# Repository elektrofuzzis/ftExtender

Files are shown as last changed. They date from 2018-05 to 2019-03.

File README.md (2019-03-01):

# ftExtender

<p align="center">Der ftExtender im fertigen Gehäuse</p>

*** english text below ***

Der I²C-Bus am TX(T) ist universell. Es lassen sich Sensoren und Aktoren für alle Anwendungsfälle anschließen und auch der ftDuino kann als preiswertes Erweiterungsboard am TX(T) angeschlossen werden. Der hier vorgestellte ftExtender löst die immer wiederkehrenden Themen
Versorgungspannung, Logikspannung und der Anschluss mehrerer Devices, so dass für den Anschluß von I²C-Geräten nur noch das passende
Kabel benötigt wird.

Das Projekt kann ebenfalls in Arduino und Raspberry Pi Projekten eingesetzt werden.

Im wiki https://github.com/elektrofuzzis/ftExtender/wiki sind Benutzung und Nachbau des ftExtender beschrieben. Der ftExtender ist als fertiges Gerät verfügbar und kann hier bestellt werden: https://gundermann-software.de/shop

Der ftExtender ist ein Community-Projekt von www.ftcommunity.de.

------------------------------------------------------------------------------------------------------------------------------------------

Using the build in I²C-interface of fischertechnik TX and TXT controllers, you could connect all types of I²C devices. You could connect a ftDuino and us it as a simple I/O extension in RoboPro, too. But if you want to use a I²C device, you need to discuss logic levels and a power supply, first. This project solves these problems and you just need some cables to connect your devices.

You could use the ftExtender in your Arduino or Raspberry Pi projects, too.

The wiki https://github.com/elektrofuzzis/ftExtender/wiki describes usage and reprodution of the ftExtender. The ftExtender is available as a ready-made system, too. Please visit: https://gundermann-software.de/shop

This is a community project of www.ftcommunity.de.

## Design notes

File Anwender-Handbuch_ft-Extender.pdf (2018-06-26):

## ft-Extender

ein fischertechnik-kompatibler I²C Extender

Bedienungsanleitung

Christian Bergschneider
Stefan Fuss
Björn Gundermann
Rudenz Schulz

26.06.2018

Projekt-Homepage: https://github.com/elektrofuzzis/ft-Extender

Kontakt: | ft-extender@gundermann.org
Forum: | https://forum.ftcommunity.de/

Einleitung

Aktuell gibt es 3 verschiedene Controller im fischertechnik Umfeld die sich leicht per I²C erweitern lassen.

Dies sind der fischertechnik TX Controller

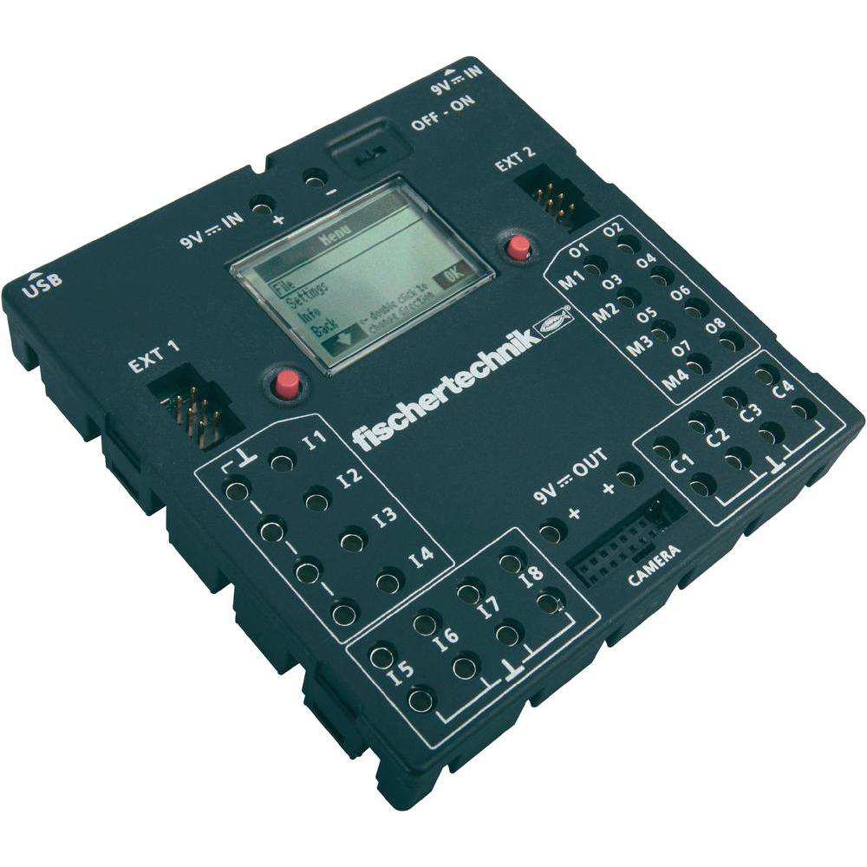
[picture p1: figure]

Der fischertechnik TXT Controller

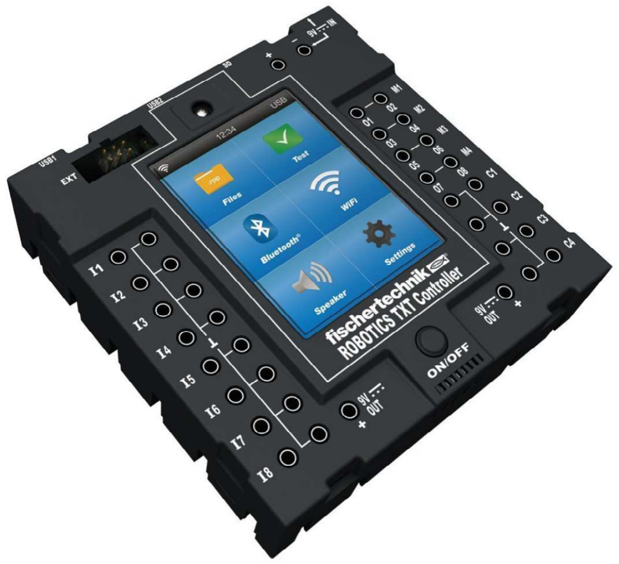
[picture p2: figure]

sowie der ftDuino auf Arduino Basis

An die Controller lassen sich Sensoren und Aktoren für alle Anwendungsfälle anschließen und auch der ftDuino kann als preiswertes Erweiterungsboard am TX(T) genutzt werden. Theoretisch, denn für jedes neue Device müssen die Themen Versorgungspannung und Logikspannung gelöst werden.

Der ft-Extender stellt beide elektrischen Standards und die benötigten Versorgungsspannungen an seinen Anschlüssen zur Verfügung, so dass der Anschluss eines I²C-Devices nur noch ein einfaches Kabel ist.

I²C
I²C ist als Master-Slave-Bus konzipiert. Ein Datentransfer wird immer durch einen Master initiiert; der über eine Adresse angesprochene Slave reagiert darauf. Der TX und TXT-Controller kann immer nur als Master agieren. Der ftDuino kann sowohl Master als auch Slave sein. Die jeweilige Variante wird per Sketch programmiert.

Jedes I²C-fähige IC hat eine vom Hersteller festgelegte Adresse, von der bisweilen die untersten drei Bits (Subadresse genannt) über drei Steuerpins festgelegt werden können. In diesem Fall können bis zu acht gleichartige ICs an einem I²C-Bus betrieben werden. Wenn nicht, müssen mehrere gleiche ICs mit getrennten I²C-Bussen angesteuert oder abgetrennt werden.

Es ist also bei Anschluss mehrerer Sensoren/Aktuatoren darauf zu achten, dass alle Teilnehmer verschiedene IDs haben.

Besitzer eines ftDuinos können die Adresse eines Teilnehmers leicht mit dem folgenden Sketch ermitteln.

Das Testprogramm sucht am I²C-Bus nach angeschlossenen Sensoren und gibt deren Adresse aus.

Da der ftDuino sowohl Master als auch Slave sein kann, ist die Kopplung zweier ftDuinos möglich.

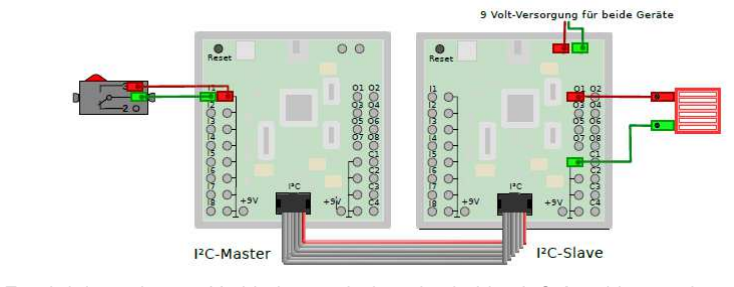
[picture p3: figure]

Es wird dazu eine 1:1-Verbindung zwischen den beiden I2C-Anschlüssen der beteiligten Controller hergestellt. Ein Controller muss in diesem Aufbau als Master konfiguriert werden und einer als Slave. Mehr dazu im Handbuch des ftDuino.

Ist ein TX/TXT Controller im Bus müssen alle anderen Teilnehmer als Slave konfiguriert werden.

Logikspannung & Stromversorgung

Beim Anschluss eines I²C-Devices hat man immer wieder die gleichen Fragestellungen nach Stromversorgung und Logikspannung.

Die ft-typischen 9V können als Stromversorgung nicht direkt verwendet werden. Alle I²C-Devices benötigen entweder 3,3V oder 5V. Diese Spannungen lassen sich mit einem Linearregler und zwei Elkos einfach herstellen.

Das gleiche gilt für die Logikspannung, auch hier gibt es I²C-Devices mit 5 V und mit 3,3 V Logikspannung.

Mit sogenannten Levelshiftern lassen sich Devices mit unterschiedlicher Logikspannung miteinander verbinden. Diese kann man mit zwei MOS-FETs und vier Widerständen selber bauen, oder fertige kleine Platinen kaufen.

Der ft-Extender löst die beiden Probleme, indem er einen Levelshifter und zwei Linearregler auf der Platine hat. Somit können problemlos 5 V- und 3,3 V-Devices ohne Zusatzbeschaltung über ein einfaches Kabel angeschlossen werden.

Als Stromversorgung stehen 250 mA für jedes angeschlossene Device zur Verfügung. Dies ist für den Betrieb von Sensoren völlig ausreichend. Beim Anschluss von Aktoren wie Motoren, Lampen und Servos sind 250 mA schnell erreicht, so dass diese eine eigene Stromversorgung bekommen sollten.

Anschlüsse

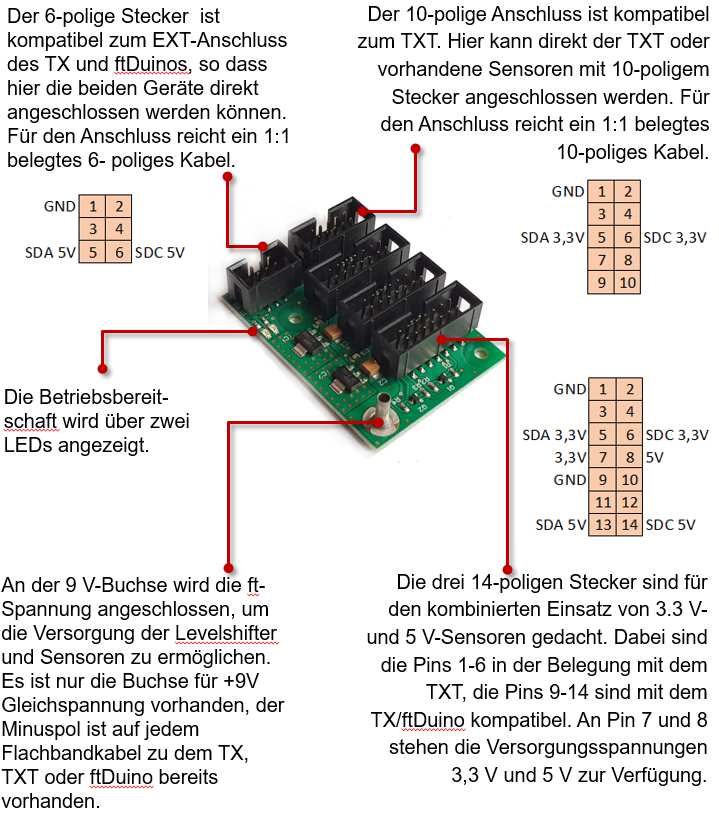
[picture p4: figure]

Anwendungsbeispiele

Für die meisten Beispiele existieren ROBOPro Bibliotheken oder ftDuino Programme. Die Links hierzu finden Sie am Ende des Handbuchs.

TX- und TXT Controller
Der TX-Controller wird immer über ein 1:1 gecrimptes Flachbandkabel am 6-poligen Stecker angeschlossen. Der TXT-Controller wird immer über ein 1:1 gecrimptes Flachbandkabel am 10-poligen Stecker angeschlossen.

Die fischertechnik Firmware der beiden Controller beherrscht leider keinen Multi-Masterbetrieb am I²C-Bus. Deshalb können nicht mehrere TX- oder TXT-Controller über den I²C-Bus zusammengeschaltet werden.

Mit der CFW-Firmware kann der TXT-Controller als Slave-Device programmiert werden. In diesem Fall lassen sich mehrere fischertechnik Controller zusammenschalten.

ftDuino Grundschaltung
Der ftDuino wird wie der TX in der Regel am 6-poligen Stecker über ein 1:1 gecrimptes Flachbandkabel angeschlossen.

Im Gegensatz zu den original fischertechnik Controllern kann der ftDuino sowohl als Master- als auch als Slave-Device programmiert werden. Im Slave-Modus können mehrere ftDuinos am ft-Extender angeschlossen werden.

ftDuino als Erweiterungsboard am TX(T)
Über den ft-Extender lassen sich ftDuinos als Erweiterungsboards an den TX und TXT-Controller anschließen. Dabei wird der oder die ftDuinos als I²C-Slave-Device programmiert und vom original fischertechnik Controller unter ROBOPro gesteuert.

Will man nun einen TXT und einen ftDuino koppeln, so wird wie gewohnt der TXT am 10-poligen Stecker und der ftDuino am 6-poligen Stecker
angeschlossen.

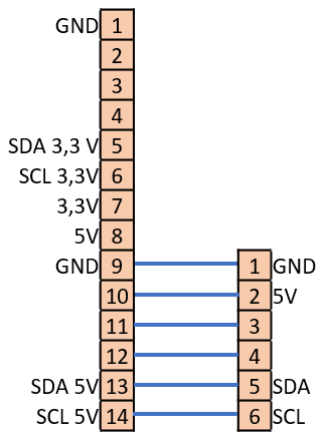
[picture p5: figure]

Soll der ftDuino mit dem TX gekoppelt werden, oder
sollen | mehrere | ftDuinos | an | einem | Controller
angeschlossen werden, so müssen die ftDuinos an den 14-poligen Steckern angeschlossen werden.

Dazu wird ein 6-poliges Flachbandkabel auf die letzten 6 Anschlüsse einer 14-poligen Buchse gecrimpt. Das zweite Ende des Flachbandkabels erhält eine 6-polige Buchse.

0,96“ OLED-Display
Es gibt von verschiedenen Herstellern aus der Arduino-Szene fertige OLED-Displays mit I²C-Bus-Interface.

Alle Implementierungen haben einen 4poligen Stecker mit GND, VCC/VDD, SDA und SCL. Sie funktionieren in der Regel sowohl mit 3,3V als auch mit 5V. Wer sich nicht sicher ist, startet erst einmal mit 3,3V.

Achtung, die Steckerbelegung des OLED Displays kann je nach Hersteller abweichend sein!

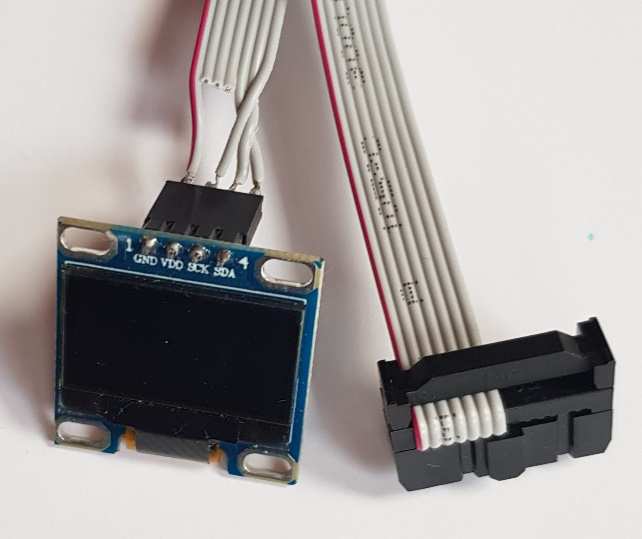
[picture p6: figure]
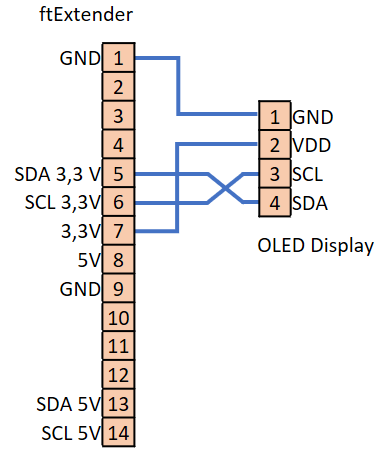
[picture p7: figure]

Um das Kabel leichter crimpen zu können kann auch ein 14-poliges Flachbandkabel AWG28 verwendet werden. Nicht benötigte Kabel können dann später gekappt werden. Dies vereinfacht das crimpen des Kabels. Das gecrimpte Kabel sollte auf jeden Fall danach noch einmal geprüft werden.

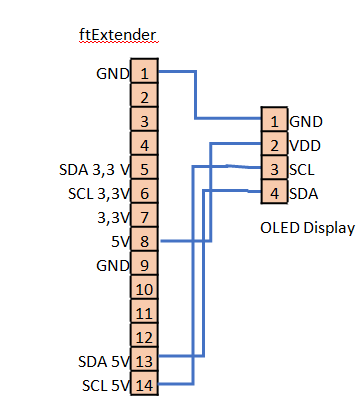
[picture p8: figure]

Die Belegung für ein Display mit 5Vsieht wie folgt aus.

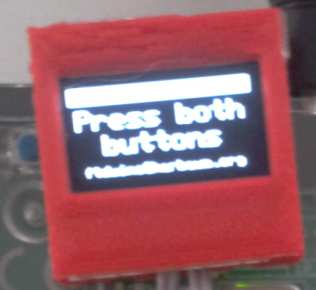
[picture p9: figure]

Ein Fertiggerät (ft-OLED) aus Display und 3D-gedrucktem
Gehäuse | kann | über | ft-extender@gundermann.org
bezogen werden. Wahlweise mit 6pol oder 14pol

Pfostenbuchse.

ft-Extender kaskadieren

Sind alle Buchsen des ft-Extenders belegt, so kann man auch mehrere ft-Extender hintereinander schalten. Dazu können entweder die 10-poligen oder die 6-poligen Stecker mit einen 1:1-Kabel verbunden werden.

Mit einem 6-poligen und einem 10-poligen Kabel können auch drei ft-Extender zusammengeschaltet werden. Wichtig ist, dass keine Schleifen entstehen: zwei ft-Extender, die sowohl mit einem 6-poligen als auch einem 10-poligen Kabel verbunden sind funktionieren nicht. Dies ist auch der Grund warum ein 14-poliges Kabel ebenfalls nicht funktioniert – hier sind bereits beide Signalpegel enthalten und würden eine Schleife bilden.

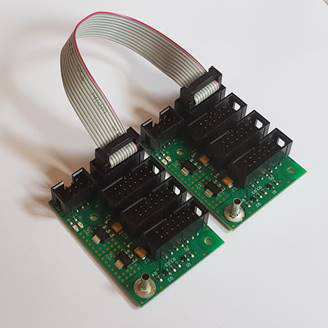
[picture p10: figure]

8x8 BiColor LED Matrix

Die 8x8 BiColor LED Matrix von Adafruit ist eine LED Matrix bestehend aus 64 Pixeln. Jedes Pixel besteht aus einer 2-Farb-LED und kann somit die Farben rot, grün und orange darstellen. Die Ansteuerung der LED Matrix erfolgt über den I²C-Bus mit einem 5V-Signal.

Da eine Versorgungsspannung benötigt wird, erfolgt der Anschluss am 14-poligen Stecker:

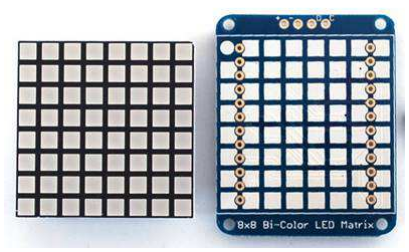
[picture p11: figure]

Adafruit hat neben der beschriebenen 8x8-BiColor Matrix auch noch einfarbige Matrizen, Bargraphs und 7-Segmentanzeigen im Programm. Das elektrische Anschlussschema und der verwendete I²C-Bus-Steuerbaustein ist für alle Typen gleich. Der ROBOPro-Treiber funktioniert mit allen 8x8-Matrizen. Bei den anderen Typen funktioniert die Ansteuerung des I²C-Bus-Steuerbausteins und das Ein- und Ausschalten einzelner LEDs. Eine ausführliche Beschreibung der LED-Matrix- und 7-Segmentanzeigen von Adafruit finden Sie im Link Kapitel.

Sparkfun 7-Segmentanzeige

Mit einem anderen Treiberbaustein ausgestattet ist die 7-Segmentanzeige COM-11440 von Sparkfun. Sie kann wahlweise mit 3,3V oder mit 5V betrieben werden. In diesem Beispiel wird der 5V-Anschluss verwendet. Der Anschluss am 14-poligen Stecker:

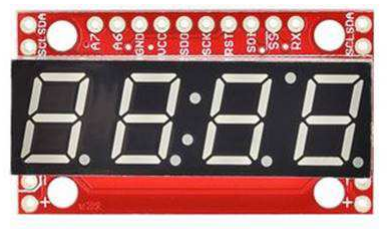
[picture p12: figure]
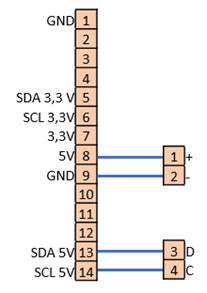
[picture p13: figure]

Der Baustein und seine Ansteuerung ist in der ft:pedia 4/2016 ab Seite 84 im Detail von Dirk Fox beschrieben. Der Link zu den Treibern findet sich im Link Kapitel.

VL53L0X LIDAR-Distanzsensor

Dieser Sensor ist eine interessante Alternative zu Ultraschallsensor. Statt Schall wird hier mit einem gemessen

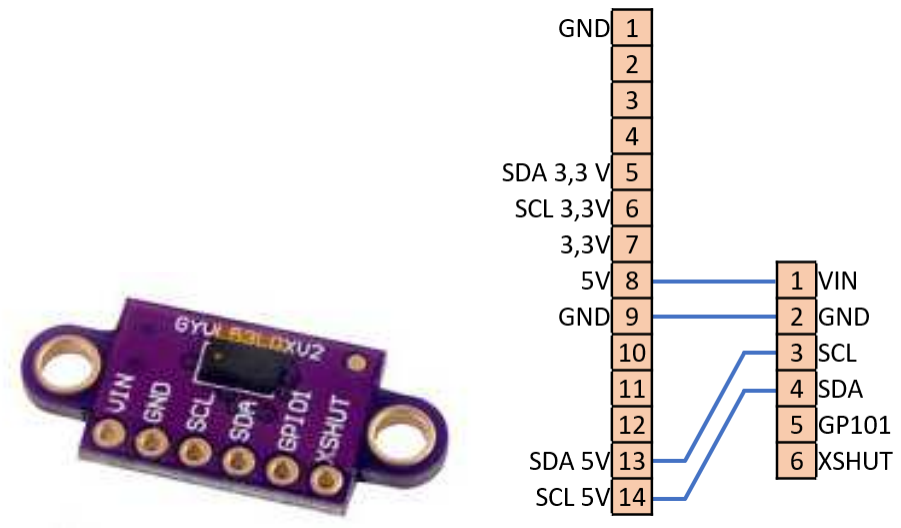
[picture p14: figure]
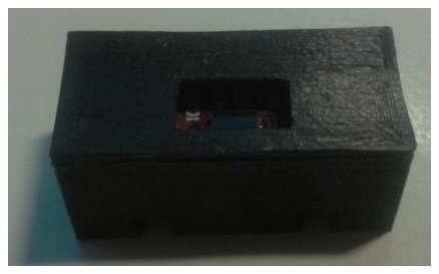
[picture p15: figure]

Ein Fertiggerät (ft-LIDAR) aus gedrucktem Gehäuse kann über extender@gundermann.org

TCS34725 RGB Sensor
Der TCS34725 ist ein hochwertiger Farbsensor und er
dem fischertechnik Farbsensor (der nur einen Hell
weniger störlichtanfällig und verlässlichere Farbbestimmung. sowohl mit 3,3V als auch mit 5V betrieben werden.

dem fischertechnik
Laserlicht die Entfernung

Sensor und 3Dftbestellt werden.

möglicht, im Gegensatz zu
igkeitswert liefert), eine schnellere, Der Sensor kann

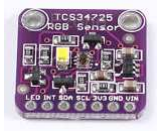
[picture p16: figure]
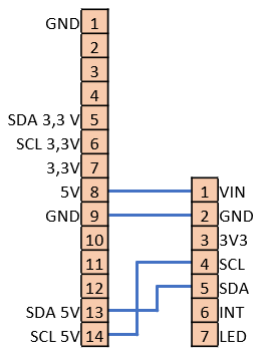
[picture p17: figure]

Fischertechnik Kombisensor und TXT Smart Home Senso

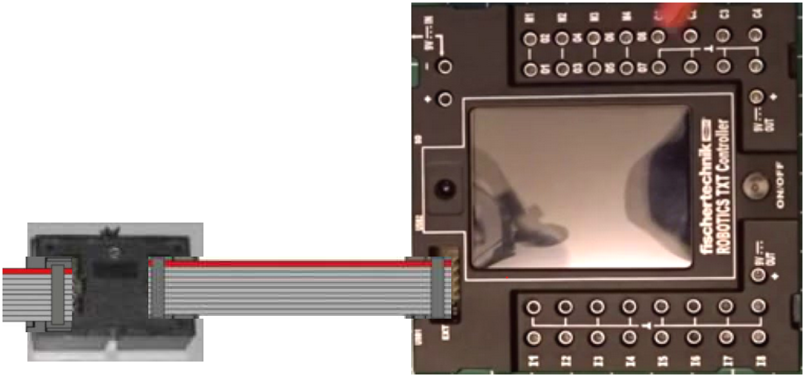
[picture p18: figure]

Diese Sensoren kommen mit dem
Weiterhin verfügen diese Sensoren über 2 Wannenstec über die beiden Stecker 1:1 geschleift, so dass es Möglichkeiten gibt:

TXT

- Der Sensor wird über ein 10 über ein zweites 10-poliges Kabel.
- Der Sensor wird am 14
ersten 6 Pins von 14
Steckers verbunden. Die Pins 7 verbunden werden!

r

für den TXT gebräuchlichen 10 poligen Kabel. ker. Das I²Cfür den Anschluss mehrere

-poliges Kabel angeschlossen, der
poliges Kabel.
-poligen Stecker angeschlossen. Dabei werden die -poligen Stecker mit den ersten 6 Pins des 10
-10 des 10-poligen Steckers dürfen

-Bussignal ist

ft-Extender

-poligen
nicht

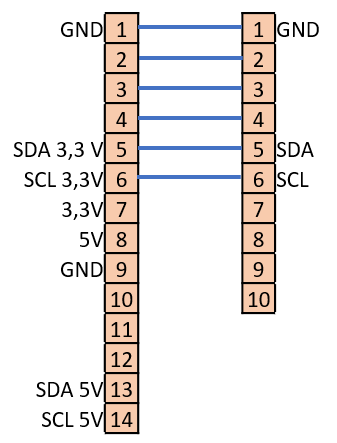
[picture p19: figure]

TX und ftDuino

TX bzw. ftDuino werden über ein 6

- Der Sensor wird über ein 10
- Der Sensor wird am 14
ersten 6 Pins von 14
Steckers verbunden. Die Pins 7 verbunden werden!

-poliges Kabel am ft-Extender angeschlossen.

-poliges Kabel am ft-Extender angeschlossen. -poligen Stecker angeschlossen. Dabei werden die -poligen Stecker mit den ersten 6 Pins des 10
-10 des 10-poligen Steckers dürfen nicht

angeschlossen.

angeschlossen.

-poligen

Crimpen von Flachbandkabeln

Die Pfostenbuchsen an den Flachbandkabeln lassen sich auch ohne Spezialwerkzeug crimpen.

An der Buchse ist Pin1 mit einem Pfeil markiert. Für ein 1:1-Kabel wird hier die farblich markierte Ader des Flachbandkabels angelegt. Ob das Kabel links oder rechts aus der Buchse geführt wird ist völlig egal, die Pinbelegung am Kabel bleibt gleich. Wichtig ist, dass das Kabel möglichst senkrecht zur Buchse geführt wird, damit zu keinem Kurzschluss kommt.

Danach wird entweder mit einer Wasserpumpenzange oder mit dem Schraubstock der Sicherungsclip auf die Buchse gedrückt. Dabei wird das Flachbandkabel automatisch gecrimpt. Bitte nicht mit zu viel Kraft, die Sicherungsclips brechen sonst gerne.

I²C Sensoren mit direktem Anschlußkabel an TX/ftDuino als Beispiele

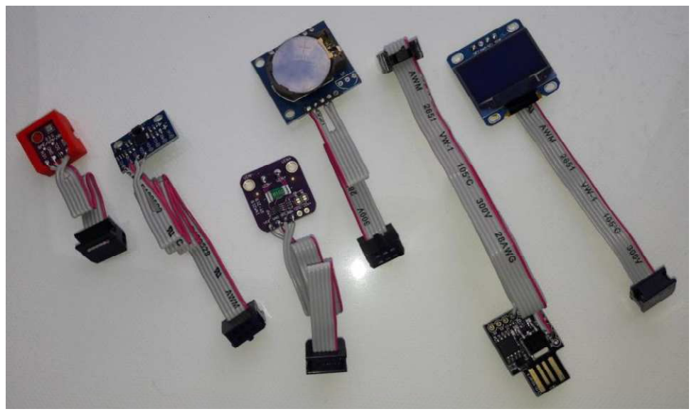
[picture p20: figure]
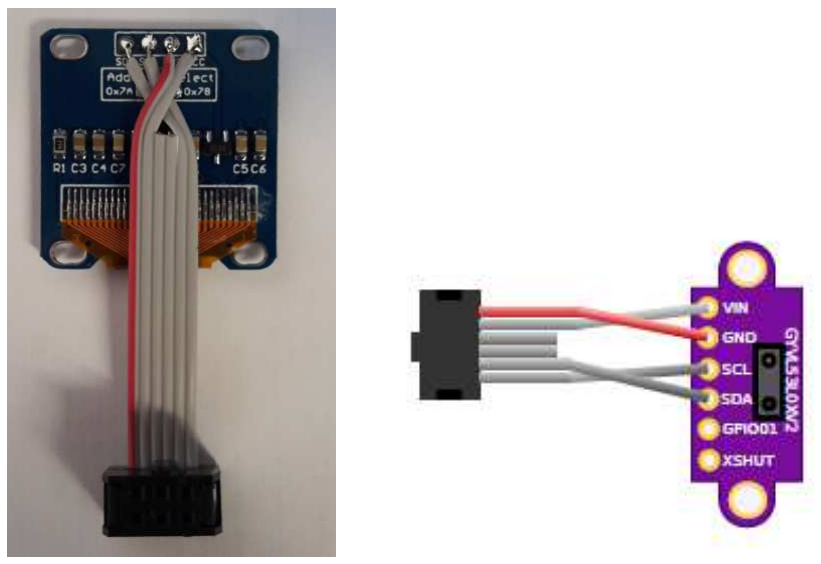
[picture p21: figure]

Technische Daten

Alle Flachbandkabel benötigen einen Leitungsabstand von 1,27mm.

Die Pfostenbuchsen haben ein Rastermaß von 2,54mm.

Der Spannungsregler hat eine maximale Ausgangsleistung von ca. 800mA. Eine höhere Gesamtlast kann also nicht an den 3 Anschlüssen verwendet werden. Normale Sensoren liegen jedoch deutlich unter diesem Wert.

An der 9V Buchse ist die 9V Versorgung des TX, TXT oder ftDuino mit den normalen ft-Kabeln und deren Stecker anzuschließen.

Steckerbelegungen kompakt:

6-pol TX/ftDuino | 10-pol TXT | 14-pol Sensoren/Aktuatoren

Pfostenbuchsen

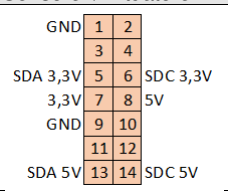
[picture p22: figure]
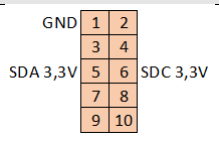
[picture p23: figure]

Die notwendigen Pfostenbuchsen können wie das Flachbandkabel direkt mitbestellt werden.

Eine Suche nach „Pfostenbuchse, 6-polig„ findet passende Treffer. Als reines Beispiel sei in der Anlage der Link vermerkt. Es besteht keine Verbindung zu der genannten Firma. Alternative Bezugsquellen existieren ebenfalls.

Wichtig ist es auf das Rastermaß von 2,54mm zu achten.

Anhang A: Schaltplan

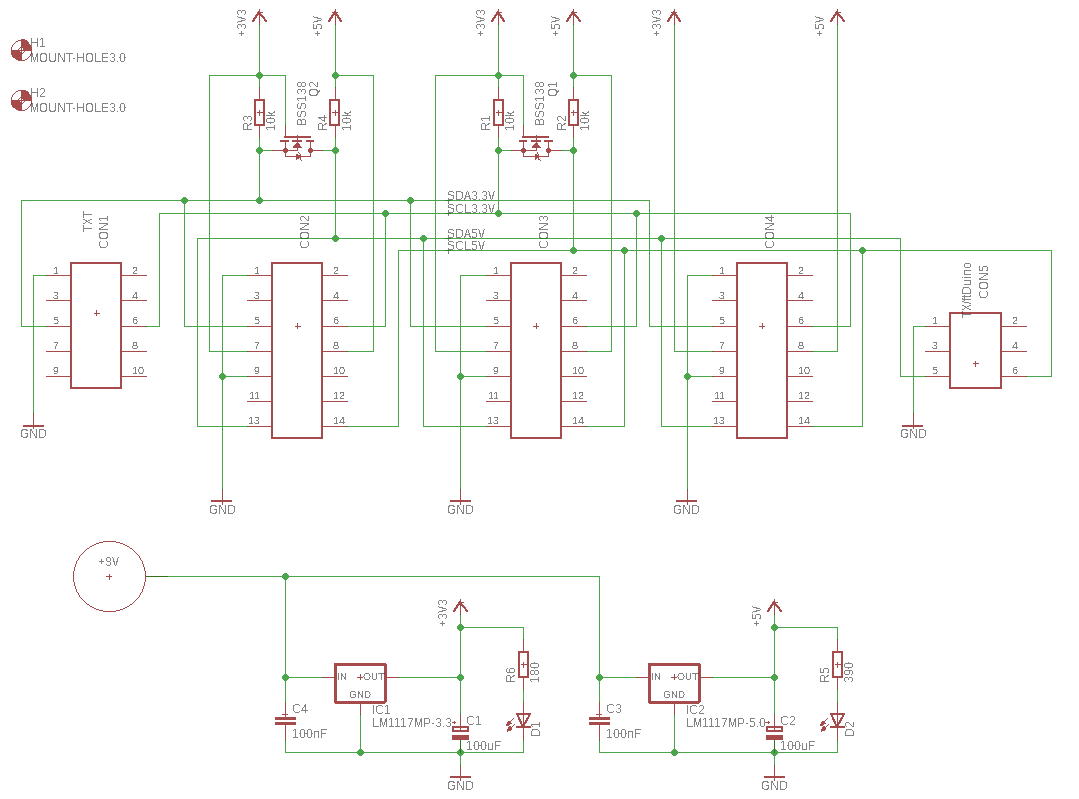
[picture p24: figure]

Links

Hier eine Liste von sinnvollen Links zu Treibern und weiteren Informationen

ftDuino | fischertechnik compatible arduino | www.Ftduino.de info@ftduino.de Till Haarbaum
Fischertechnik | Hersteller des TX/TXT Controllers | www.fischertechnik.de
I²C | Serieller Datenbus | https://de.wikipedia.org/wiki/I%C2%B2C
I²C | Treiber Sammlung | https://github.com/ControlEverythingCommunity
Ft-Extender | Bilder/Video Fertigung | https://www.dropbox.com/sh/hyrzibvc3apt … – Zy8a?dl=0
Ft-Extender | Produktseite | http://www.gundermann.org
Ft-Extender | Technische Infos | https://github.com/elektrofuzzis/
OLED ROBOPro Bibliothek | Nutzung des OLED Displays am TX/TXT | https://github.com/elektrofuzzis/oled
ftDuinoTX-T | Nutzung des ftDuino als Erweiterung für den TX/TXT | https://github.com/elektrofuzzis/ftDuinoTX-T-
8x8 ROBOPro Bibliothek | 8x8 BiColor LED Matrix | https://github.com/elektrofuzzis/ftpiLED
Adafruit LED/7-Segment | Ausführliche Beschreibung der LED-Matrix- und 7-Segment-anzeigen von Adafruit | https://cdn-learn.adafruit.com/downloads/pdf/adafruit-led-backpack.pdf
Sparkfun ROBOPro Treiber | | https://www.ftcommunity.de/data/downloads/robopro/leds7sdtreiberv1.0.zip
VL53L0X LIDAR | Arduino Bibliothek | https://github.com/adafruit/Adafruit_VL53L0X
Farbsensor TCS34725 | Ft:pedia Artikel | Dirk Fox: I²C mit dem TX(T) - Teil 13: Farbsensor. ft:pedia 1/2016, S. 79-89. Inkl. ROBOPro Treiber
Farbsensor TCS34725 | ams ( TAOS) Datenblatt | TCS3472 Color Light to digital Converter with IR Filter
Pfostenbuchse | Beispiel Link von Reichelt | https://www.reichelt.de/Pfosten-Wannenstecker/PFL-6/3/index.html?ACTION=3&GROUPID=7437&ARTICLE=53153

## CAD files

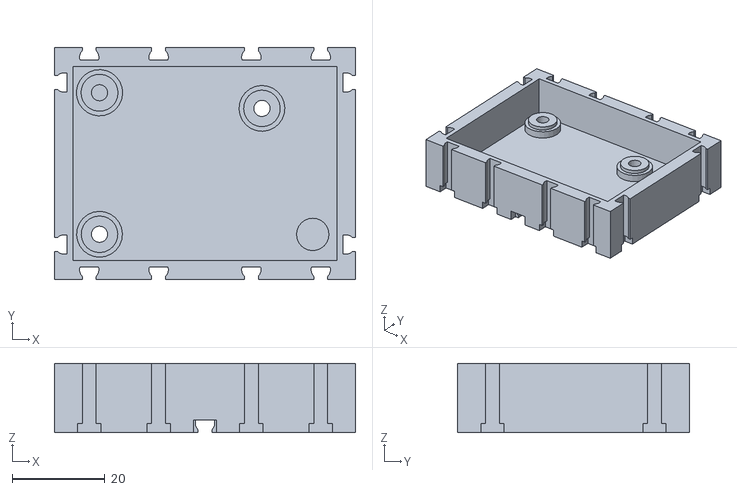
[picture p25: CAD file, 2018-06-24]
Gehauese/I2C-V5.stl
65.0 x 50.0 x 15.0

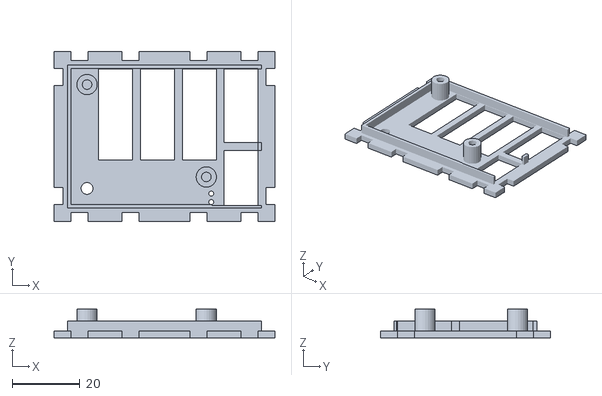
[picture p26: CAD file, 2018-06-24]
Gehauese/I2C-Top-V9.stl
65.0 x 50.0 x 8.50

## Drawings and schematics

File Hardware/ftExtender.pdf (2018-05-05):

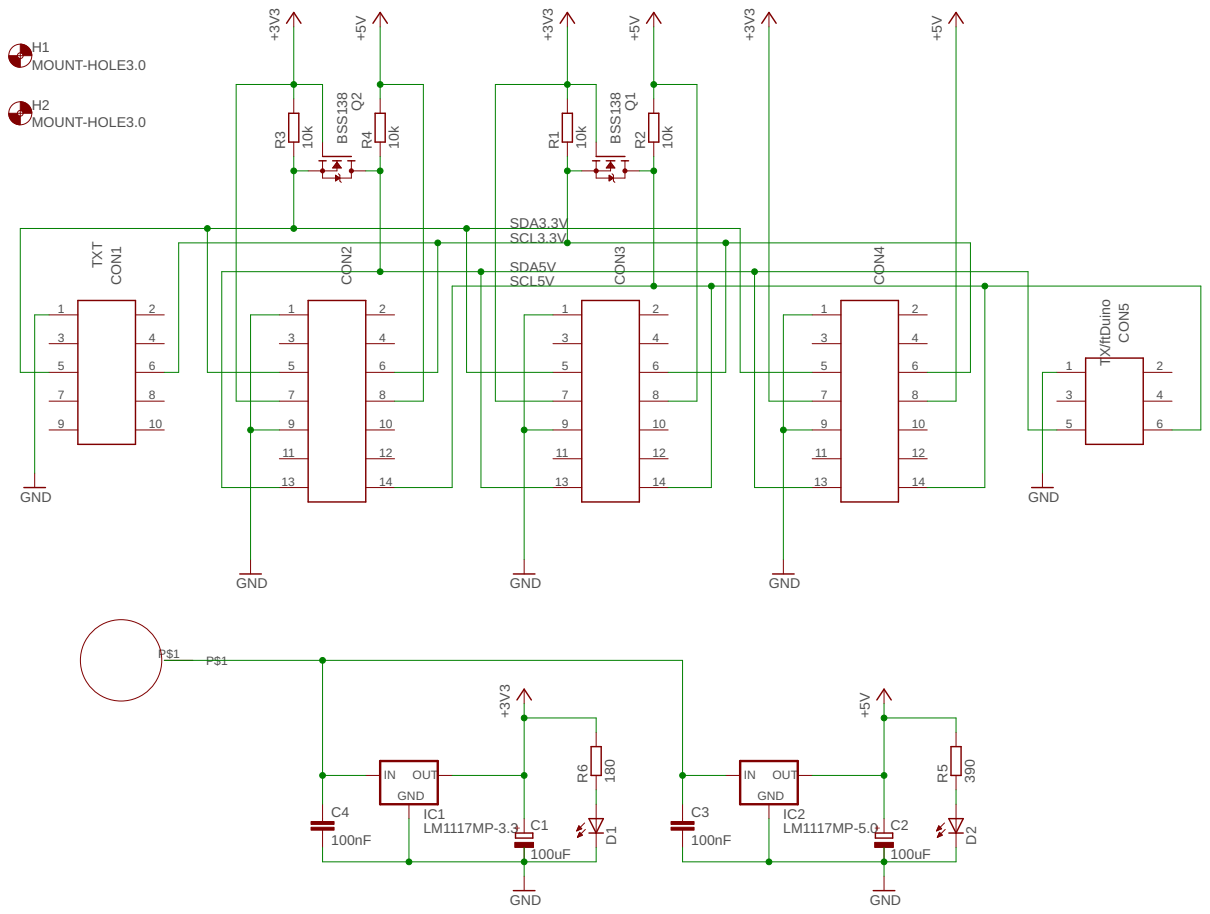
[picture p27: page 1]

SCL3.3V

SDA5V
SCL5V

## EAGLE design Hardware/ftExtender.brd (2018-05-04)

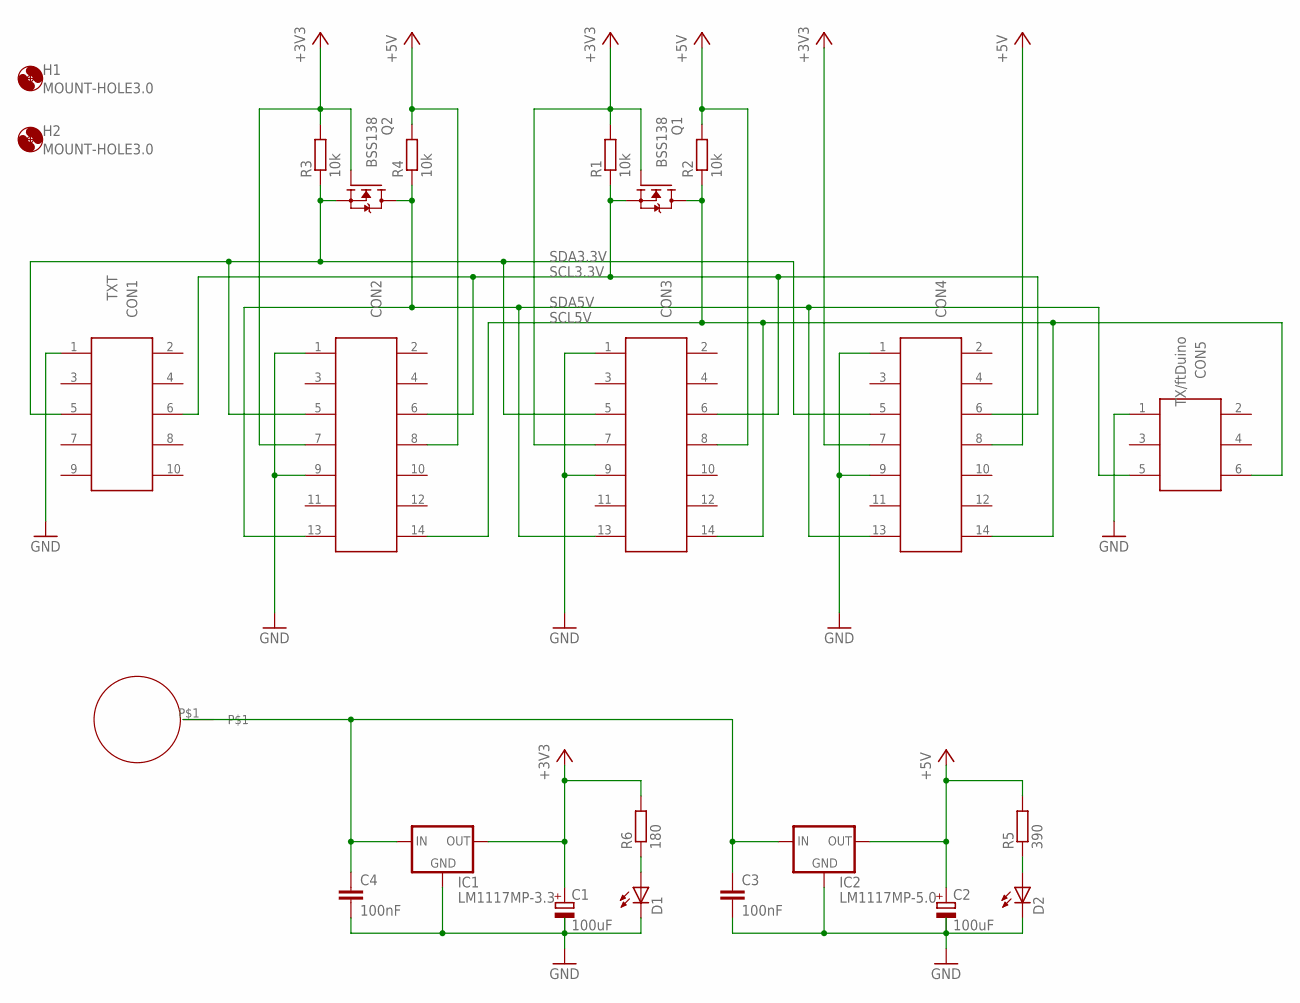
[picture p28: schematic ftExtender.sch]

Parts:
+9V: BUNDHUELSE
C1, C2: 100uF; CT3528
C3, C4: 100nF; C0603K
CON1: TXT; 612X1020621
CON2, CON3, CON4: 612X1420621
CON5: TX/ftDuino; SMTHEADER06
D1, D2: LEDCHIP-LED0805; CHIP-LED0805
H1, H2: MOUNT-HOLE3.0; 3,0
IC1: LM1117MP-3.3; SOT223
IC2: LM1117MP-5.0; SOT223
Q1, Q2: BSS138; SOT23
R1, R2, R3, R4: 10k; R0603
R5: 390; R0603
R6: 180; R0603

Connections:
+3V3: C1.- (+), CON2.7, CON3.7, CON4.7, IC1.2 (OUT), IC1.4 (OUT), Q1.1 (G), Q2.1 (G), R1.2, R3.2, R6.2
+5V: C2.- (+), CON2.8, CON3.8, CON4.8, IC2.2 (OUT), IC2.4 (OUT), R2.2, R4.2, R5.2
+9V: +9V.P$1, C3.1, C4.1, IC1.3 (IN), IC2.3 (IN)
GND: C1.+ (-), C2.+ (-), C3.2, C4.2, CON1.1, CON2.1, CON2.9, CON3.1, CON3.9, CON4.1, CON4.9, CON5.1, D1.C, D2.C, IC1.1 (GND), IC2.1 (GND)
unnamed: D2.A, R5.1
unnamed: D1.A, R6.1
SCL3.3V: CON1.6, CON2.6, CON3.6, CON4.6, Q1.2 (S), R1.1
SCL5V: CON2.14, CON3.14, CON4.14, CON5.6, Q1.3 (D), R2.1
SDA3.3V: CON1.5, CON2.5, CON3.5, CON4.5, Q2.2 (S), R3.1
SDA5V: CON2.13, CON3.13, CON4.13, CON5.5, Q2.3 (D), R4.1

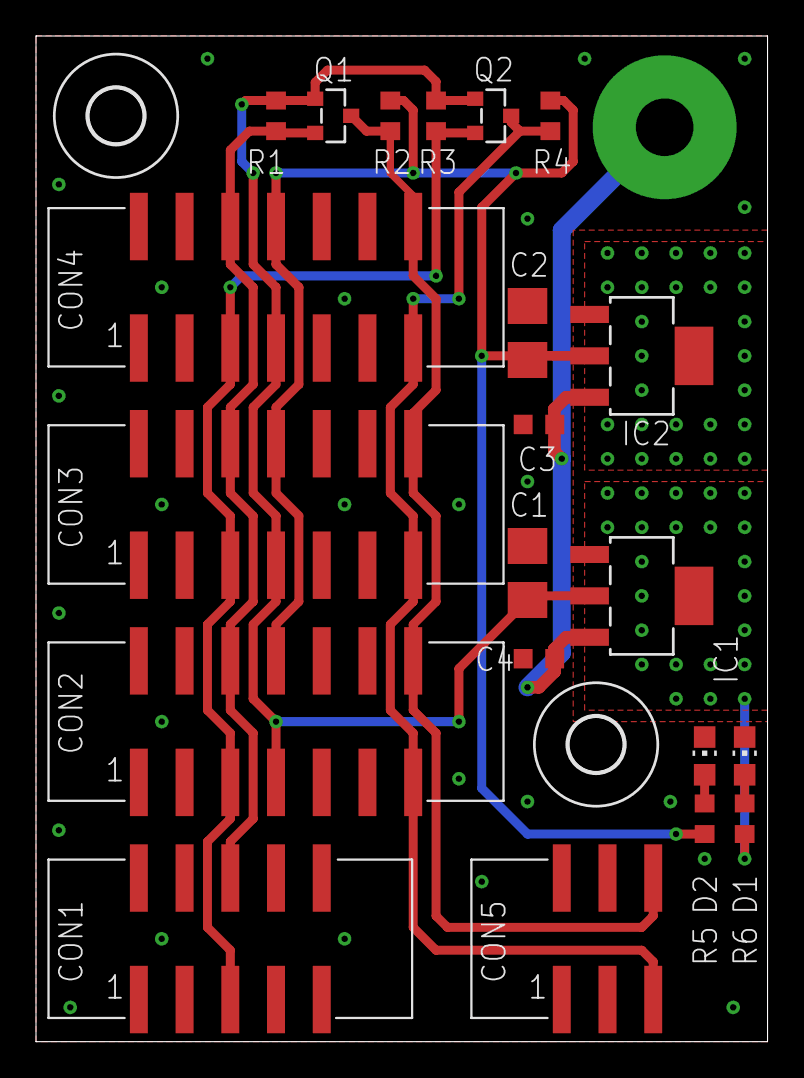
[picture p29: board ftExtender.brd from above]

Board: 2 copper layers, 40.6 x 55.9 mm, 24 parts (0 on the bottom side), 10 nets.

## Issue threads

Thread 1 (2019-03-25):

Pinbelegung unklar

PeterDHabermehl, 2019-03-25:
Hallo zusammen,
bei der Pinbelegung muss man ein bisschen raten - die Zeichnungen der Pinbelegung bieten keine Orientierungshilfe. Schaue ich auf Stecker oder Buchse, von vorn / hinten?

Gruß
Peter

elektrofuzzis, 2019-03-28:
Hallo Peter,

am der Buchsenleiste an die Du Dein Flachbandkabel crimpst, gibt es auf einer Seite einen Pfeil. Dieser Pfeil zeigt auf PIN 1 - normalerweise crimpt man dahin die rote Ader. Dann hat dein Flachbandkabel automatisch die richtige Reihenfolge 1,2,3... Das passt dann zu den Angaben auf dem Schaltplan.

Gruss

Stefan

Am 26. März 2019 00:47:00 MEZ schrieb Peter Habermehl <notifications@github.com>:
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

--
Diese Nachricht wurde von meinem Android-Gerät mit K-9 Mail gesendet.

PeterDHabermehl, 2019-03-28:
Ja.. genau.. oh Mann, manchmal sieht man den Wald vor lauter Bäumen nicht -
ich habe die Führungsnut gesucht... Elektronik-Hardware sollte halt lieber
jemand Anderes machen :-)

Danke
Peter

Am Donnerstag, 28. März 2019, 17:59:15 CET schrieb elektrofuzzis:
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

Closed 2019-03-29.

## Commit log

2018-05-04 initial version
    [ftExtender.brd, ftExtender.sch]
2018-06-24 stl added
    [I2C-Top-V9.stl, I2C-V5.stl]

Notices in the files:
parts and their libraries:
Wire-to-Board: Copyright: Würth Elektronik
